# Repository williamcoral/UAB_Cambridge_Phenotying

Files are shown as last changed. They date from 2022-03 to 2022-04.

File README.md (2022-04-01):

# UAB_Cambridge_Phenotying
Weight Measuring Component
Hello Marius
This is the repository where you can find the requested circuit. Because some of the device features were not specified in your message, such as:
1. Sampling rate
2. Communication protocol for communication between sensors and microcontroller.
3. How to program the microcontroller and display the data.
4. Type of power supply to be used
5. Where the data will be displayed
6. Operating voltage
7. EMI-EMC

Thanks to this lack of information, I took certain liberties in the design of the circuit, such as:
1. Sampling rate will be 1k samples per second
2. The communication protocol will be I2C between the sensor and the microcontroller.
3. The microcontroller will be programmed through the usb port (micro USB connection). Data can be displayed using an OLED I2C panel or a computer, via the micro USB port.
4. This device will be able to work with at least two cell Lipo batteries (up to 3 cells 3S). as well as an external power supply or via a micro USB cable.
5. The data can be displayed using an OLED panel compatible with I2C communication or a computer through the USB port.
6. The input voltage range is from 4.5 to 21V.
7. mask on top and bottom layer.

I apologize in advance for taking so long to send the circuit, but from Thursday of last week to Tuesday of this week I was traveling. It was fun doing this circuit and I hope you like it.

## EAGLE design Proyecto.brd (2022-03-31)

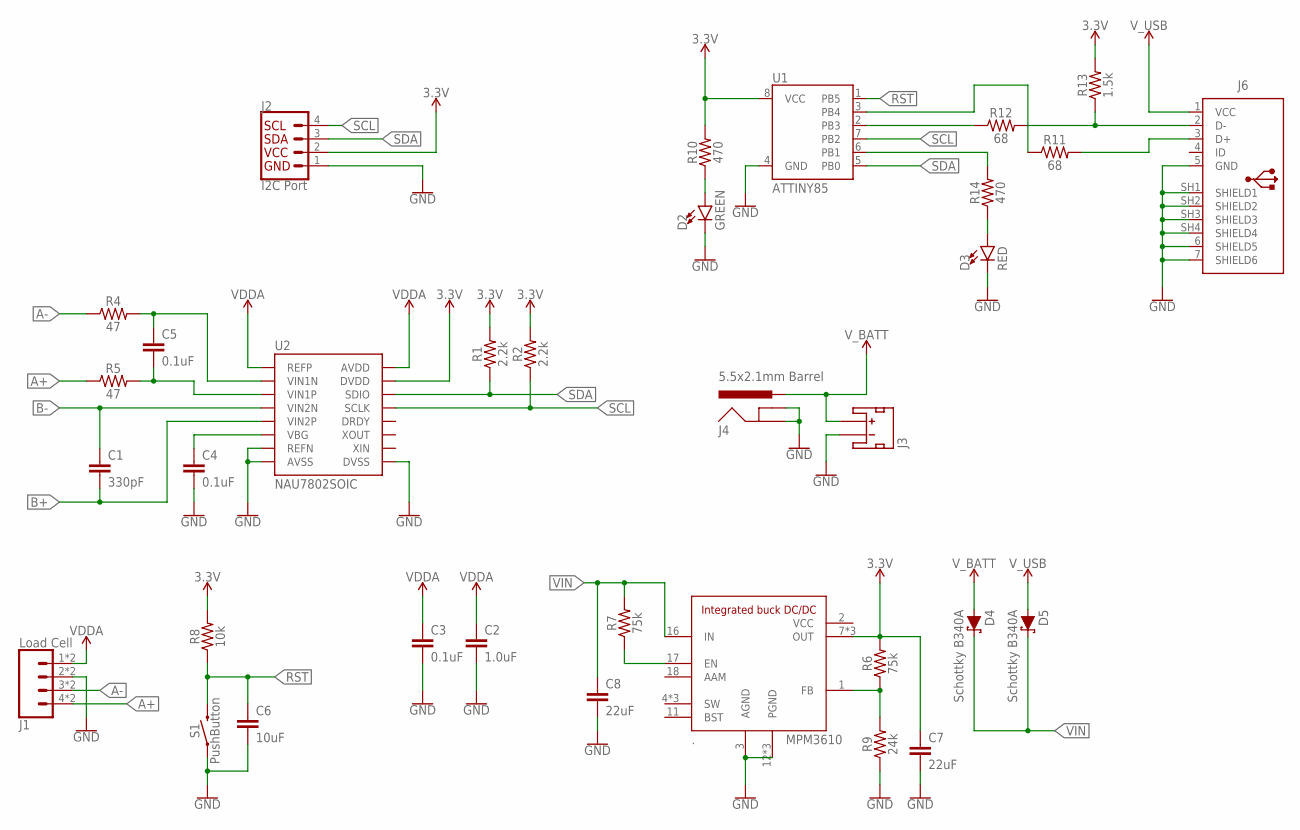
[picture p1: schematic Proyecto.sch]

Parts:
.: MPM3610; MICROBUILDER_MPM3610
C1: 330pF; 0603
C2: 1.0uF; 0603
C3, C4, C5: 0.1uF; 0603
C6: 10uF; 0603
C7, C8: 22uF; 1206
D2: GREEN; LED-0603
D3: RED; LED-0603
D4, D5: Schottky B340A; SMA-DIODE
J1: Load Cell; 1X04_SPRING_TERMINAL
J2: I2C Port; JST04_1MM_VERT
J3: JST_2MM_MALE; JST-2-SMD
J4: 5.5x2.1mm Barrel; POWER_JACK_SMD
J6: 10103594
R1, R2: 2.2k; 0603
R4, R5: 47; 0603
R6, R7: 75k; 0603
R8: 10k; 0603
R9: 24k; 0603
R10, R14: 470; 0603
R11, R12: 68; 0603
R13: 1.5k; 0603
S1: PushButton; TACTILE_SWITCH_SMD_5.2MM
U1: ATTINY85
U2: NAU7802SOIC; SO16

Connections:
3.3V: ..7 (OUT), ..8 (OUT), ..9 (OUT), C7.1, J2.2, R1.2, R2.2, R6.2, R8.2, R10.2, R13.2, U1.8 (VCC), U2.15 (DVDD)
A+: J1.4, J1.8 (4), R5.1
A-: J1.3, J1.7 (3), R4.1
B+: C1.2, U2.5 (VIN2P)
B-: C1.1, U2.4 (VIN2N)
GND: ..3 (AGND), ..12 (PGND), ..13 (PGND), ..14 (PGND), C2.2, C3.2, C4.2, C6.2, C7.2, C8.2, D2.C, D3.C, J1.2, J1.6 (2), J2.1, J3.1 (-), J4.GND (GNDBREAK), J4.P$4 (GND), R9.1, S1.1, S1.2 (1), U1.4 (GND), U2.7 (REFN), U2.8 (AVSS), U2.9 (DVSS)
unnamed: R11.1, U1.3 (PB4)
unnamed: C4.1, U2.6 (VBG)
unnamed: ..1 (FB), R6.1, R9.2
unnamed: D3.A, R14.1
unnamed: C5.1, R4.2, U2.2 (VIN1N)
unnamed: C5.2, R5.2, U2.3 (VIN1P)
unnamed: ..17 (EN), R7.1
unnamed: R14.2, U1.6 (PB1)
unnamed: J6.3 (D+), R11.2
unnamed: R12.1, U1.2 (PB3)
unnamed: J6.2 (D-), R12.2, R13.1
unnamed: D2.A, R10.1
RST: C6.1, R8.1, S1.3 (2), S1.4 (2), U1.1 (PB5)
SCL: J2.4, R2.1, U1.7 (PB2), U2.13 (SCLK)
SDA: J2.3, R1.1, U1.5 (PB0), U2.14 (SDIO)
SHIELD5: J6.5 (GND), J6.6 (SHIELD5), J6.7 (SHIELD6), J6.SH1 (SHIELD1), J6.SH2 (SHIELD2), J6.SH3 (SHIELD3), J6.SH4 (SHIELD4)
VCC: ..2 (VCC)
VDDA: C2.1, C3.1, J1.1, J1.5 (1), U2.1 (REFP), U2.16 (AVDD)
VIN: ..16 (IN), C8.1, D4.C, D5.C, R7.2
V_BATT: D4.A, J3.2 (+), J4.VIN0 (PWR)
V_USB: D5.A, J6.1 (VCC)

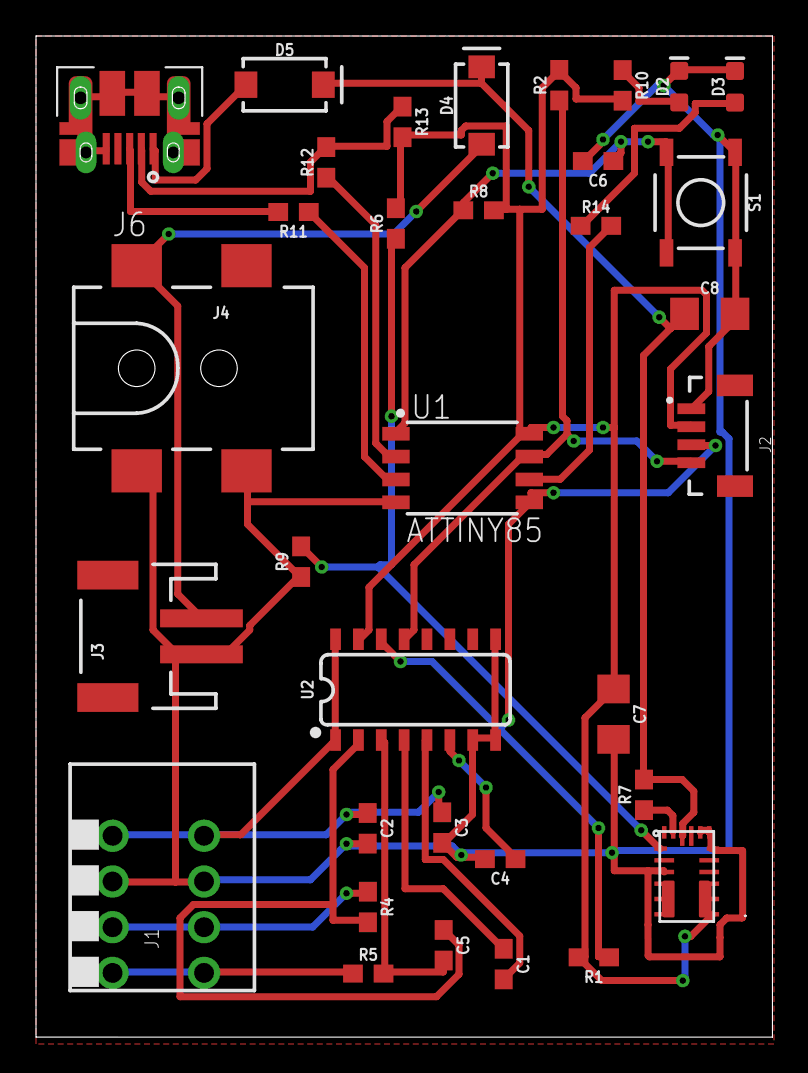
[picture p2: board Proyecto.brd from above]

Board: 2 copper layers, 40.9 x 55.6 mm, 34 parts (0 on the bottom side), 26 nets.

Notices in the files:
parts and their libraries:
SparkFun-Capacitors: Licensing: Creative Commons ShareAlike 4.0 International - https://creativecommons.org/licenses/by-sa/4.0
